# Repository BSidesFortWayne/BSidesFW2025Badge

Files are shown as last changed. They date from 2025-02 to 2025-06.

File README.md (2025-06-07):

# BSidesFW2025Badge

## How to use your badge

Here are some basic instructions to get you started using your BSides 2025 Badge!

### Navigating the Menu

When your badge initially boots it will load the default badge application and show your name.
If you would like to explore other features of the badge, you can press and hold (long press) button D.

Button D is located at the top corner of the badge and can be long pressed while using any of the
applications to return to the main menu.

### Badge Button Descriptions

RST: Pressing RST will reset the badge.

A: Function button, varies by App.

B: Function button, varies by App.

C: Function button, varies by App.

D: Long press (hold) D to return to menu screen from any App.

SEL: SEL (Select) button is used in most Apps and the Menu for making a selection.

(Left): Used in Apps and Menu to navigate Left or Down.

(Right): Used in Apps and Menu to navigate Right or Up.

### Badge App Functionality

(Left): This button will cycle through available colors for the font.

(Right): This button will cycle through available colors for the background.

A: This button will change the lower display to have the BSides Fort Wayne 2025 logo.  
++++_note: using the (Left) or (Right) buttons will switch the display back to showing company name and status_++++

D: Long press (hold) D to return to the Main Menu

Settings will save between power cycles.

## Development: Getting Started

### Tools

The python packages in this repository are managed by `uv`. The repository structure is as follows

- `.venv`: This folder will be installed when you set up the python virtual environment with uv
- `.vscode`: Vscode specific settings for this project
- `schematics`: Board schematics as PDF
- `src`: The embedded code for deployment on the target
- `STLs`: Screen bezels, supports, and PCB STLs
- `typings`: Custom typings for the VSCode Python Language Server in order to get better typehints and support for the micropython code

### Setup

Install `uv` ([getting started](https://docs.astral.sh/uv/getting-started/installation/)) based on your OS of choice. If on Windows, you may have a better development experience in `WSL` if you can provide access to the ESP32 chip to the WSL instance ([Connect USB devices](https://learn.microsoft.com/en-us/windows/wsl/connect-usb)). However, `uv` and `mpremote` both work on Windows so you can also develop natively

### Using `mpremote` for on board development

Once you have `uv` setup, you can simply run

```shell
uv sync
```

to get the virtual environment set up. Once you plug in and turn on your dev board, you need to change the device permissions (Linux only)

```shell
sudo chmod a+x /dev/ttyUSB0
```

Please see [The Programming Guide](./PROGRAMMING.md) for more details

### Hardware

Please see [The Hardware Specifications](./HARDWARE.md) for more details

### Off Board Unit Tests

`pytest` is used to run any hardware independent unit tests in the `tests/` folder with
the following command

```shell
uv run pytest tests
```

This runs the pytest command out of the `tests` folder.

TODO: Perhaps we can reference the src/ folder so that we can move the files in `src/test` to
`tests` to keep as functional tests? But they are different in that we will run the functional
onboard tests with `mpremote run src/test/<test_file.py>`

## Custom Base Image Instructions

```bash
# Move to BSFW Custom Firmware
cd BSidesFW2025Badge/firmware

# Sync uv with project
uv sync

# Erase current flash and write new flash binary
uv run esptool.py erase_flash
uv run esptool.py --baud 460800 write_flash 0x1000 BSFWCustom_firmware_SPIRAM_with_GC9A01.bin
```

Please see the [Firmware Writeup](./firmware/README.md) for more information.

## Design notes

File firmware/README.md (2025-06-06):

# Custom Badge Firmware

Our custom badge firmware binary was developed with C modules and drivers already compiled into the MicroPython source code. This firmware is required for the CTF challenges as many of the challenges rely on custom C compiled into the MicroPython image in order to operate.

**BSFWCustom_firmware_SPIRAM_with_GC9A01.bin** - This binary includes MicroPython 1.26.0, our custom Badge Challenges, and the Russ Hughes GC9A01 MicroPython C-Based Display driver.

The binary can be easily flashed to your board with the following commands:

```shell
uv run esptool.py erase_flash
uv run esptool.py --baud 460800 write_flash 0x1000 <location_of_your_downloaded_bin_file>

# e.g.
uv run esptool.py --baud 460800 write_flash 0x1000 ~/Downloads/BSFWCustom_firmware_SPIRAM_with_GC9A01.bin
```

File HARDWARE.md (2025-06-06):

## Technical Specifications V4

This section describes the technical specifications of the board to aid in development.

### Schematic Overview

Within the [schematics/Badge Schematic V4.pdf](https://github.com/commputethis/BSidesFW2025Badge/blob/68bb887bfc6d0544537c8bf179ed645db8c0f13b/schematics/BSides%20Badge%20V2%20Schematic.pdf) you will find the electrical schematic of the device including the part numbers and connections between components identified as net labels. Each section of the schematic will be described below and applicable datasheets will be linked.

### ESP32-WROVER-E-N8R8

This section contains the ESP32-WROVER-E-N8R8 itself, the decoupling capacitors, the pullup resistors required for operation of the I2C Bus, and the net labels associated with the GPIO pins of the ESP32. The ESP32-WROVER-E-N8R8 has a 240Mhz Dual Core processor with 8Mb of Flash and 8Mb of RAM available on the SPI bus.

Datasheets:
[ESP32 Wrover E/IE](https://www.espressif.com.cn/sites/default/files/documentation/esp32-wrover-e_esp32-wrover-ie_datasheet_en.pdf)

### USB-Serial

This board uses a CH340C USB to Serial chip to allow for programming via USB-C connector. When connected to USB-C your computer should detect a USB to Serial interface resulting in the creation of a COM port much like any ESP32 or Arduino style device.

### USB-C

This section contains the USB-C shell connector and associated netlabels. CC1 and CC2 are connected to 5.1k resistors to request basic 5V low power from the USB-C device connected. DP and DN data connectors are connected to the CH340C to facilitate communication with the ESP32 via the UART.

### WS2812B

This section contains the seven WS2812 RGB LEDs connected to IO26. There is not much more to say about this. Treat it like a small LED strip.

[Worldsemi WS2812B-B/T](https://www.lcsc.com/product-detail/RGB-LEDs-Built-in-IC_Worldsemi-WS2812B-B-T_C2761795.html)

### RTS/DTR Circuit

This section contains a dual transistor package that is used to place the ESP32 into programming mode and reset mode based on the RTS/DTR output of the CH340C driven by the attached programming software application.

### Boot/Function Buttons

These are the four buttons across the top of the device, to the right of the ESP32, and three gaming buttons. SW1 is dual-purpose. During normal operation, it serves as a simple button attached to IO0. However, IO0 is a strapping pin dedicated to placing the ESP32 into the boot (programming) mode. If SW1 is held during startup, the device will be manually placed into boot mode. This should not be required during normal programming sessions, as the RTS/DTR circuit should handle this function, but it is available if needed in special circumstances. SW2, SW3, SW4, SW7, SW8, and SW9 are basic buttons connected to a PCA9535 IO expander at address 0x20 on the I2C bus. All lines are pulled high and are active low.

SW1 > IO0

SW2 > IO1_2

SW3 > IO1_1

SW4 > IO1_0

SW7 > IO0_2

SW8 > IO0_1

SW9 > IO0_0

### Reset Button

Connected to the EN pin of the ESP32. Pressing this will reset the device.

### LIS3DHTR Accelerometer I2C Address 0x18

This section contains the accelerometer (LIS3DHTR) and the associated connections. The datasheet is linked for reference. The I2C data lines are connected to IO22 (SCL) and IO21 (SDA) on the ESP32, and the accelerometer can be accessed at I2C address 0x18. IO34 is also dedicated to a programmable interrupt pin on the accelerometer for possible use. An example of this device would be for power saving. If no motion is detected for an interval, the device could be put into a reduced power state and then later woken up using the interrupt pin. Of course, there are plenty of other fun things that can be accomplished using the three-axis output of the accelerometer. The unused interrupts and ADC inputs are wired to the expansion headers for future use.

Datasheet: [LIS3DH](https://www.st.com/resource/en/datasheet/lis3dh.pdf)

### Battery Monitor

This is a straightforward voltage divider that represents the current voltage of the LIPO 3.7V nominal battery. It is read via ADC1 on the Accelerometer on the I2C bus. The divider ratio is 0.2985, resulting in a fully charged battery at 4.2V sending 1253 mV to ADC1, and a fully discharged battery at 3.0V will result in 895 mV at ADC1. Admittedly, this is not the best method of determining battery charge status, but it's better than nothing, and with some simple code to average the readings and correct the non-linearity of LIPO discharge rates, it can be effective at gauging basic SOC levels.

### DW01A Battery Protection

This is a safety feature to prevent damage to the battery due to overcharging or over-discharging. It will disable the battery in the event of any anomaly. It's a very commonly used circuit to manage single-cell lithium battery safety.

### Battery Charger TP4056

This is a single-cell lithium battery charger circuit. It will charge at up to ~900ma using the power delivered from the USB-C VBUS and will manage the charging of the lithium cell. Two LEDs indicate charge status. Red = Charging, Green = Fully Charged.

### Boost Buck 3V3

This is the primary switching power converter and takes its input from the VCC network (Post power switch, battery protection, and fuse) and converts that into a stable 3.3V for the board Components. This power module (TPS63060DSCR) is a boost buck module and can accept input voltages in a wide range to deliver a consistent 3.3V output. This module is running anytime the power switch is in the on position and a battery is connected.

Note: This device is not designed to operate without a battery. The battery provides voltage stability that the boost buck converter requires for reliable operation. Operating the device from USB power with no battery is not recommended and will result in undesirable power fluctuations.

### Power Switch

Simple... It's a switch. Turn it on to use it.

### Display Headers

These are the 7-pin female headers that the screens plug into and the transistors that control the display's power. The DISP_EN network is connected to IO32, which controls the power status of the displays. Bringing IO32 high will enable the displays, and bringing it low will disable them. IO32 can be used to save power when not in use. By default, IO32 is pulled low, and the displays will be off normally.

The Screens are connected to the SPI data bus and can operate independently via software using the Data Control, Reset, and Chip Select Pins. The pinouts are below.

Common Pins for SPI Bus:

MOSI > IO23

CLK > IO18

Screen 1 Pins:

DC1 > IO19

RST1 > IO14

CS1 > IO33

Screen 2 Pins:

DC2 > IO25

RST2 > IO27

CS2 > IO13

### Speaker

There is a "speaker" (really a variable frequency buzzer). You can send tones by adjusting the PWM frequency and varying the volume by changing the PWM duty cycle, although this method may yield mixed results at different frequencies. This is connected to IO15 of the ESP32. Datasheet below:

[HYDZ HYG-7525A-5027](https://www.lcsc.com/product-detail/Buzzers_HYDZ-HYG-7525A-5027_C18623827.html)

### Expansion Headers

V2 contains two expansion headers. In V4 these will not be populated with headers and will be available to anyone who wants to hack these devices and use IO that is not used by anything else on the board. The Pinouts are referenced on the Schematic as well as the silkscreen on the back of the board. (H3 and H4). H4 is closest to the top of the board.

### Input/Output Expander 0x20

This is a PCA9535 IO expander at address 0x20 on the I2C bus IO22 (SCL) and IO21 (SDA). The PCA9535 provides an additional 16 GPIO lines via the I2C bus and in this application is used to read the status of buttons. For details about the buttons refer to the Boot/Function Buttons section. The unused IO lines are wired to the expansion headers for future use.

### ESP32 GPIO Pin Assignments

IO0    Boot/Button 1 (Strapping)

IO2    (Strapping) Not Connected

IO4    (Strapping) Not Connected

IO5    (Strapping) Not Connected

IO12   (Strapping) Not Connected

IO13   CS2

IO14   RST1

IO15   (Strapping) Speaker

IO18   CLK

IO19   DC1

IO21   I2C SDA

IO22   I2C SCL

IO23   MOSI

IO25   DC2

IO26   WS2812B

IO27   RST2

IO32   DISP_EN

IO33   CS1

IO34   Accelerometer Interrupt

IO35   Not Connected

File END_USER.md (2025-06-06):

# End User Usage

## Types of Users

- [ ] Badge Barry
  - Programs badge at registration, never touches
  - Cares about a badge that runs all day/low power detection mode
- [ ] Tinkerer Tina
  - Wants to play around with their badge to try apps or change settings
  - Might connect their badge to WiFi
  - Need better on-board configuration and app selections
- [x] Script Kiddie Sam
  - Wants to modify existing apps and write basic code
  - May be overwhelemed by project setup but can use WiFi landing page to modify or upload new single-file apps
- [x] Hacker Hanna
  - Wants to set up the dev environment on their computer to play with the badge, largely by playing with the exiting micropython code base, but wants to do it in their editor for full deployment control
  - Need access to the GitHub repo for the source code (to be released post conference because of CTF things on the badge)
- [x] Embedded Eddie
  - Will set up the `esp-idf` himself and load his own custom images
  - Would benefit most from schematics

## Adding custom apps

- Start up badge
- Put into AP mode
- Open page to add app /apps
  - Text editor to paste code
  - Download examples

## Modify app configurations

- Start up badge
- Put into AP mode
- Open page to change config (/config.html)
- Edit configs in recursive menu
  - Make HTML tables based on
  - `bool`, `str`, `int`, and `float` properties can be editable fields in table
  - `dict` objects in config can be sub-tables (should be avoided)

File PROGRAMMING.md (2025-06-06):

You can erase the flash and then flash the board with the above image with the following commands

```shell
uv run esptool.py erase_flash
uv run esptool.py --baud 460800 write_flash 0x1000 <location_of_your_downloaded_bin_file>

# e.g.
uv run esptool.py --baud 460800 write_flash 0x1000 ~/Downloads/firmware_SPIRAM_8MiB.bin
```

And then you can either mount the `src` directory for the board and start in a REPL

```shell
uv run mpremote mount src
```

Or deploy the source to the board directly

```shell
# This will deploy all src, but mpremote will check the hash of the files to determine 
uv run mpremote cp -r src/* :
```

Here are some other useful patterns with `mpremote`

```shell
# when developing and iterating quickly, we can use this to deploy the file you are working on and then running `main` from local
# in one command
uv run mpremote cp -r src/apps/analog_clock.py + run main.py
```

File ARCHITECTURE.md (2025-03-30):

# Architecture Diagrams

## Module/App Design Constructors

- Files (also called modules) in the `apps/` folder will be auto-ingested for potential apps to run
- A module can have multiple apps
- Apps MUST inherit from the base class
- App minimum requirements are very light
- Base App class will provide
  - Automatic app registration (thanks to app directory)
  - Automatic serialization/deserialization of configs
    - Not required to use, but helps group configs for UI and web based config edits
    - (Not Done) Support for displaying in apps menu with custom icons and names
    - (Not Done) Abstracted registraiton functions for button handling and other hardware based callbacks that can be automatically de-registered as well

## Button Constructs

- Long presses are good for "exiting" context
- Should be used minimally
- Should come up with unified button handling that is mostly outside of app control for existing an app/going back to the menu

## Main Startup Sequence

```mermaid
flowchart TD
    badgeApp["Badge App"]
    loadAppCache["Load App Cache"]
    modulesChanged{"Files Changed?"}
    showLoadingScreen["Show Loading Screen"]
    errorParsing{"Error <br> Loading New <br> Modules?"}
    reparseChangedModules["Parse Modules"]
    storeNewConfiguration["Store New <br> Configuration"]
    revertToOldConfig["Disable Module, <br> Write to error.txt"]

    loadAppCache-->
    modulesChanged--"Yes"-->
    
    showLoadingScreen-->
    reparseChangedModules-->
    errorParsing--"No"-->storeNewConfiguration-->badgeApp
    errorParsing--"Yes"-->revertToOldConfig-->badgeApp

    badgeApp

    modulesChanged--"No"-->badgeApp

```

## Config

- The base app provides a `Config` object that can allow the apps to be dynamically configured via the `/config` 
endpoint. When an app is open, the endpoint can be visited and any app settings that were registered can be adjusted. 
The `analog_clock.py` shows an example of this. Currently basic types like `str` and `int` are supported, as well as 
various smart config objects. Check out `lib/smart_config.py` for more information. The base `SmartConfig` class is
itself a dictionary for easy serialization and deserialization to a JSON config file
- Smart Config Types
  - `EnumConfig`: Allows you to specify a config object form a list of options. Renders as an HTML dropdown
  - `BoolDropdownConfig`: Inherits from enum config for boolean selection. Unfortunately HTML checkboxes don't act in 
  normal ways in HTML forms so to avoid a larger payload to patch that behavior, we just use this instead for bools
  - `RangeConfig`: Allows you to specify a number value with a range that is then rendered as an HTML slider
  - `ColorConfig`: Inherits from `RangeConfig` and specifics the normal 565 color limits for the gc9a01 display

- (Not Done) The Smart Config class will also be renderable as UI elements on the screens themeselves. The inputs
should generally match what is available on the HTML config page (sliders, dropdowns, numeric entries, etc)

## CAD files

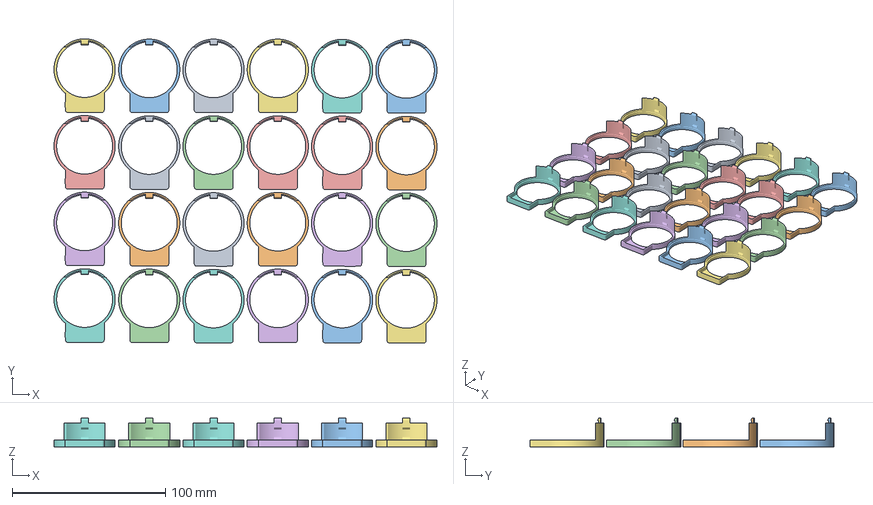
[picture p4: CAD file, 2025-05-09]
STLs/BSides2025-ScreenBezelV4_Full_Plate.3mf
250.2 x 198.8 x 18.8 mm
1.28_TFT_screen_cover_V4.stl x 2
1.28_TFT_screen_cover_V4.stl 11
1.28_TFT_screen_cover_V4.stl 2
1.28_TFT_screen_cover_V4.stl 3
1.28_TFT_screen_cover_V4.stl 4
1.28_TFT_screen_cover_V4.stl 5
1.28_TFT_screen_cover_V4.stl 6
1.28_TFT_screen_cover_V4.stl 7
1.28_TFT_screen_cover_V4.stl 8
1.28_TFT_screen_cover_V4.stl 9
1.28_TFT_screen_cover_V4.stl 10
1.28_TFT_screen_cover_V4.stl 1
1.28_TFT_screen_cover_V4.stl 12
1.28_TFT_screen_cover_V4.stl 13
1.28_TFT_screen_cover_V4.stl 14
1.28_TFT_screen_cover_V4.stl 15 x 2
1.28_TFT_screen_cover_V4.stl 16 x 2
1.28_TFT_screen_cover_V4.stl 17 x 2
1.28_TFT_screen_cover_V4.stl 18 x 2

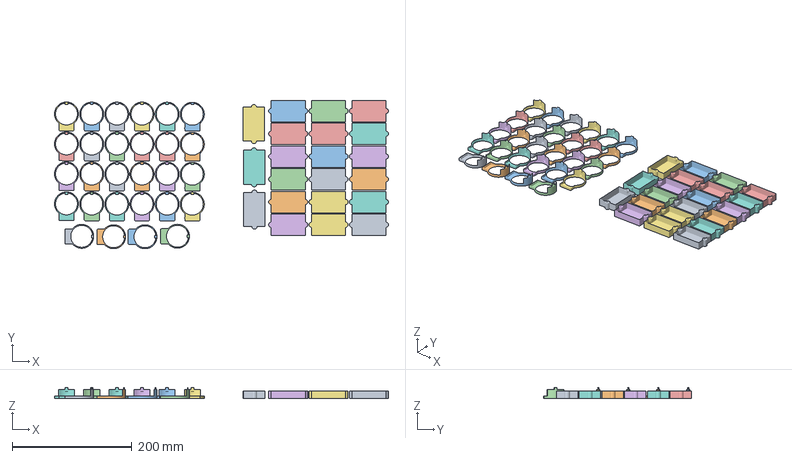
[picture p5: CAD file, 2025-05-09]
STLs/BSides2025-badge-final-print.3mf
557.9 x 248.0 x 18.8 mm
1.28_TFT_screen_cover_V4.stl x 2
1.28_TFT_screen_cover_V4.stl 11
1.28_TFT_screen_cover_V4.stl 2
1.28_TFT_screen_cover_V4.stl 3
1.28_TFT_screen_cover_V4.stl 4
1.28_TFT_screen_cover_V4.stl 5
1.28_TFT_screen_cover_V4.stl 6
1.28_TFT_screen_cover_V4.stl 7
1.28_TFT_screen_cover_V4.stl 8
1.28_TFT_screen_cover_V4.stl 9
1.28_TFT_screen_cover_V4.stl 10
1.28_TFT_screen_cover_V4.stl 1
1.28_TFT_screen_cover_V4.stl 12
1.28_TFT_screen_cover_V4.stl 13
1.28_TFT_screen_cover_V4.stl 14
1.28_TFT_screen_cover_V4.stl 15 x 2
1.28_TFT_screen_cover_V4.stl 16 x 2
1.28_TFT_screen_cover_V4.stl 17 x 2
1.28_TFT_screen_cover_V4.stl 18 x 6
BSides2025_Battery_Cover_V4.stl
BSides2025_Battery_Cover_V4.stl 17 x 4
BSides2025_Battery_Cover_V4.stl 16
BSides2025_Battery_Cover_V4.stl 1
BSides2025_Battery_Cover_V4.stl 15
BSides2025_Battery_Cover_V4.stl 14
BSides2025_Battery_Cover_V4.stl 13
BSides2025_Battery_Cover_V4.stl 12
BSides2025_Battery_Cover_V4.stl 11
BSides2025_Battery_Cover_V4.stl 10
BSides2025_Battery_Cover_V4.stl 9
BSides2025_Battery_Cover_V4.stl 8
BSides2025_Battery_Cover_V4.stl 7
BSides2025_Battery_Cover_V4.stl 6
BSides2025_Battery_Cover_V4.stl 5
BSides2025_Battery_Cover_V4.stl 4
BSides2025_Battery_Cover_V4.stl 3
BSides2025_Battery_Cover_V4.stl 2

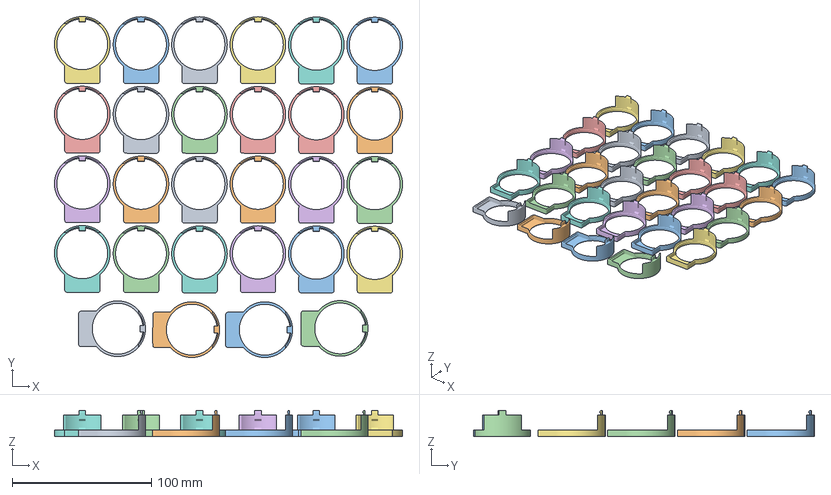
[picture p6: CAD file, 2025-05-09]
STLs/BSides2025-ScreenBezelV4.3mf
250.2 x 245.1 x 18.8 mm
1.28_TFT_screen_cover_V4.stl x 2
1.28_TFT_screen_cover_V4.stl 11
1.28_TFT_screen_cover_V4.stl 2
1.28_TFT_screen_cover_V4.stl 3
1.28_TFT_screen_cover_V4.stl 4
1.28_TFT_screen_cover_V4.stl 5
1.28_TFT_screen_cover_V4.stl 6
1.28_TFT_screen_cover_V4.stl 7
1.28_TFT_screen_cover_V4.stl 8
1.28_TFT_screen_cover_V4.stl 9
1.28_TFT_screen_cover_V4.stl 10
1.28_TFT_screen_cover_V4.stl 1
1.28_TFT_screen_cover_V4.stl 12
1.28_TFT_screen_cover_V4.stl 13
1.28_TFT_screen_cover_V4.stl 14
1.28_TFT_screen_cover_V4.stl 15 x 2
1.28_TFT_screen_cover_V4.stl 16 x 2
1.28_TFT_screen_cover_V4.stl 17 x 2
1.28_TFT_screen_cover_V4.stl 18 x 6

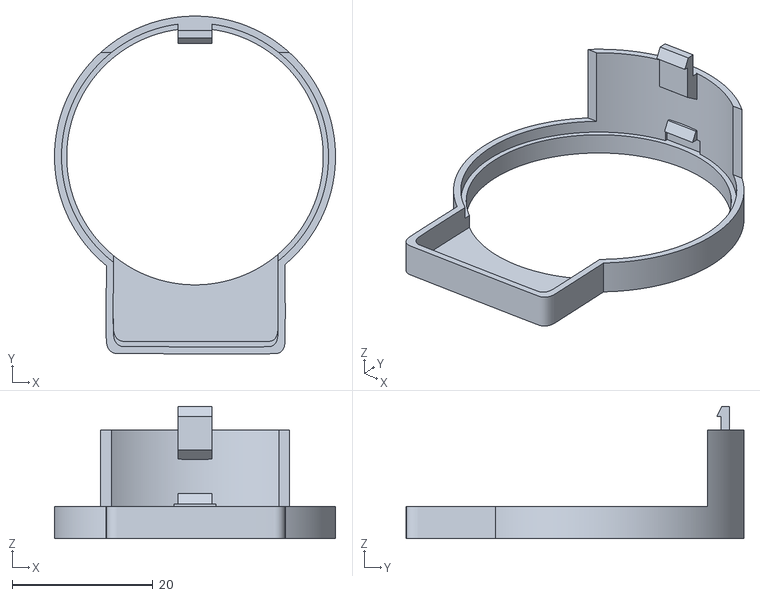
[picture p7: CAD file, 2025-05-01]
STLs/BSides2025-ScreenCoverV4.stl
40.0 x 48.1 x 18.8

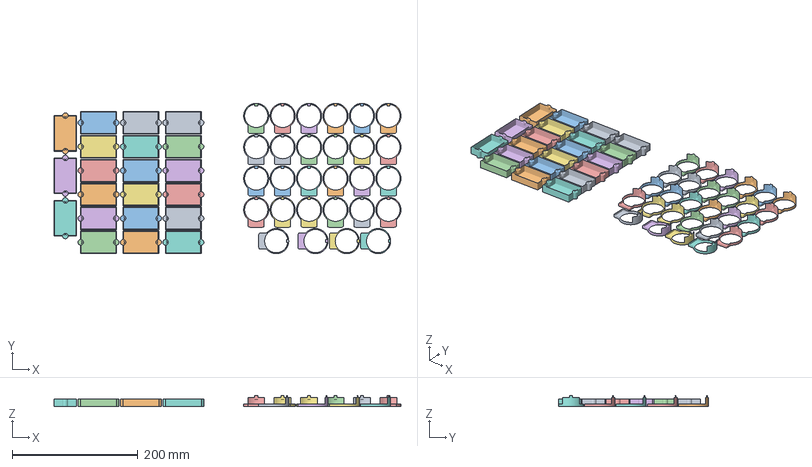
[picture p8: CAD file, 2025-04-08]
STLs/BSides2025-Badge_Covers.3mf
551.3 x 238.9 x 18.1 mm
Badge_Battery_Cover.stl 17
BSides2025-ScreenCoverV3.stl 21
BSides2025-ScreenCoverV3.stl
Badge_Battery_Cover.stl 2
BSides2025-ScreenCoverV3.stl 22
Badge_Battery_Cover.stl 3
BSides2025-ScreenCoverV3.stl 11
Badge_Battery_Cover.stl 4
Badge_Battery_Cover.stl 5
BSides2025-ScreenCoverV3.stl 2
Badge_Battery_Cover.stl 6
BSides2025-ScreenCoverV3.stl 3
Badge_Battery_Cover.stl 7
BSides2025-ScreenCoverV3.stl 4
Badge_Battery_Cover.stl 8
BSides2025-ScreenCoverV3.stl 5
Badge_Battery_Cover.stl 9
BSides2025-ScreenCoverV3.stl 6
Badge_Battery_Cover.stl 10
BSides2025-ScreenCoverV3.stl 7
Badge_Battery_Cover.stl 11
BSides2025-ScreenCoverV3.stl 8
Badge_Battery_Cover.stl 12
BSides2025-ScreenCoverV3.stl 9
BSides2025-ScreenCoverV3.stl 10
Badge_Battery_Cover.stl 13
Badge_Battery_Cover.stl 14 x 4
BSides2025-ScreenCoverV3.stl 1
BSides2025-ScreenCoverV3.stl 12
Badge_Battery_Cover.stl 15
BSides2025-ScreenCoverV3.stl 13
Badge_Battery_Cover.stl 1
BSides2025-ScreenCoverV3.stl 14
Badge_Battery_Cover.stl 16
BSides2025-ScreenCoverV3.stl 15
Badge_Battery_Cover.stl
BSides2025-ScreenCoverV3.stl 16
BSides2025-ScreenCoverV3.stl 17
BSides2025-ScreenCoverV3.stl 18
BSides2025-ScreenCoverV3.stl 19
BSides2025-ScreenCoverV3.stl 20
BSides2025-ScreenCoverV3.stl 23 x 5

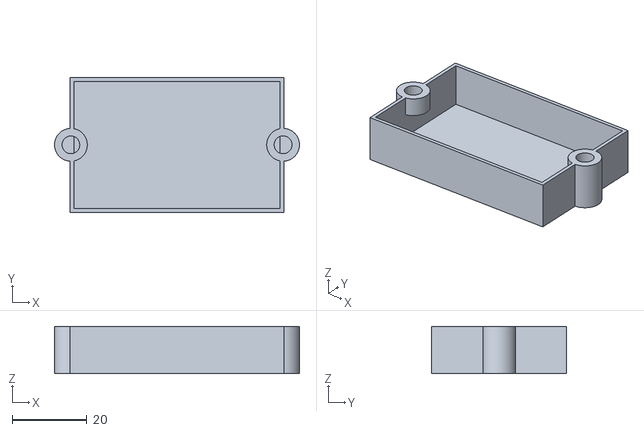
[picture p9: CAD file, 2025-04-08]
STLs/BSides2025_Battery_Cover_V5.stl
65.4 x 36.0 x 12.6

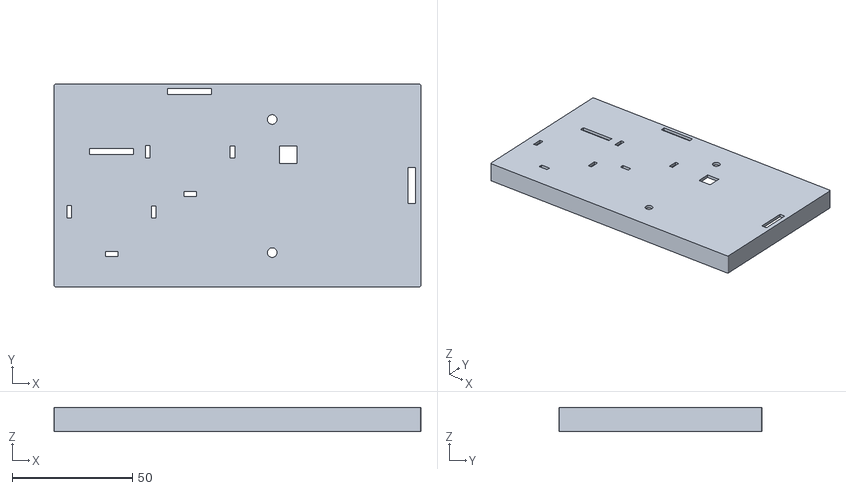
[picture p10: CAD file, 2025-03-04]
STLs/BSidesV2-Badge-Slot-Layout.stl
152.7 x 84.5 x 10.0

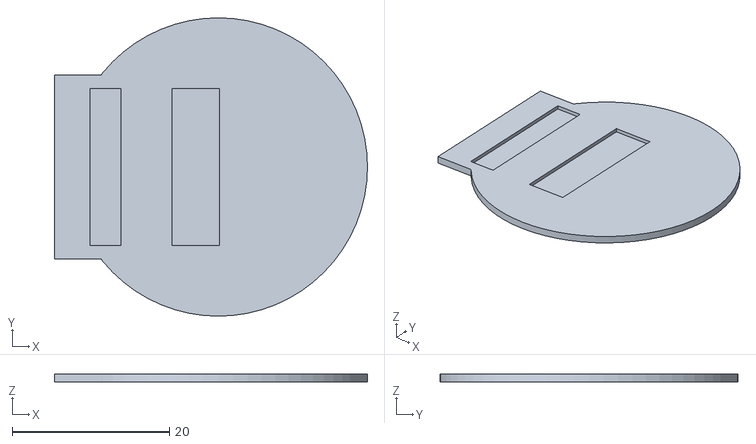
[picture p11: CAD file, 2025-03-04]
STLs/BSides2025-ScreenSupport.stl
39.9 x 38.0 x 1.05

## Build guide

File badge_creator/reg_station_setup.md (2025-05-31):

# Steps to setup registrations stations

This assumes this is a dedicated machine installed for this purpose.  This guide does not go over how to create a bootable Ubuntu usb drive.  A couple things to keep in mind:

- Keep the passwords consistent for ease of those managing the registration area
- Keep machine names consistent, but different (i.e. reg1, reg2, etc.)

## Ubuntu OS Install

1. Place the Ubuntu bootable USB drive into the powered off computer.
2. Power On the machine and boot to the USB Drive.
3. Select Install Ubuntu
4. Follow the prompts keeping the following in mind:
   1. Use Minimal install.
   2. Use "registration" as the username and login name.
   3. The password can be what ever you want, just follow the tip from above.
   4. Select the option to login automatically
   5. The rest of the options are up to you based on your preference.
5. Once the install is completed, select reboot.
6. You will then be asked to remove the USB drive and then press Enter.
7. Skip connecting online accounts.
8. Skip enabling ubuntu pro.
9. Answer how you wish on sending info to improve ubuntu
10. Location services are not needed.
11. No extra apps needed.
12. It will likely ask if you want to install updates. Proceed with doing so and restart when finished.

## Configure OS

1. Open Settings and set preferences as needed.  I do the following:
    1. Appearance - Dark theme
    2. Privacy > Screen
        1. Blank Screen Delay - Never
        2. Automatic Screen lock - off
        3. Lock Screen on Suspend - off
2. Install required components and copy scripts to the machine. This can be done by copying the badge_creator directory to the Documents directory on the registration machine and running the reg_station_setup.sh script from the machine.  So, put that on a usb drive and get it copied onto the machine.
   1. Sometimes, the run_badger_creator.sh file on the Desktop will show a lock on it in File Explorer and be owned by the root user. This will cause it not to work.  To fix that, just create a copy of the file, delete the old one, and rename the copy to the original name.
   2. The same thing happens with the /Documents/Badger_2040_Badge_Creator folder also.  Do the same thing to fix it.  However, after copying it, you can't just move it to trash, you must go to the terminal and run ```sudo rm /home/registration/Documents/Badger_2040_Badge_Creator -r```
3. Need to make the run_badger_creator.sh file be able to run as an application.
   1. Right Click on the file and select Properties.
   2. On the Permissions tab, check the Execute box
   3. Close the Properties box
4. Add Run Badger Creator to Startup Applications
   1. Open Dash (the first icon in the side bar)
   2. Click on Startup Applications
   3. Click the Add button
   4. Type in "Run Badge Creator" in Name
   5. Click the Browse button
   6. Double-click Desktop
   7. Click run_badger_creator.sh
   8. Click the Open button
   9. Click the Add button
   10. Click the Close button
5. Reboot the machine

All the remains now is to test a badge.  If for some reason the badger_gui script didn't run on startup, run it manually from terminal to see if there are errors.

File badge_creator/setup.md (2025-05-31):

# Setup Linux to be able to run these scripts

This assumes Linux (either Ubuntu or Raspberry Pi OS) is already installed.

- [Setup Linux to be able to run these scripts](#setup-linux-to-be-able-to-run-these-scripts)
  - [Install Python3](#install-python3)
  - [Install pip3](#install-pip3)
  - [Install pil](#install-pil)
  - [Install pipx](#install-pipx)
  - [Install rshell](#install-rshell)
  - [Install Tkinter](#install-tkinter)
  - [Install uv](#install-uv)
  - [Install mpremote](#install-mpremote)
  - [Add user to the dialout group](#add-user-to-the-dialout-group)

## Install Python3

Check to see if Python3 is installed by running the following from terminal:  

- `python3 -V`

If the version isn't returned, then run the following:

- `sudo apt install python3`

## Install pip3

Check to see if pip3 is installed by running the following from terminal:

- `pip3 -V`

If the version isn't returned, then run the following:

- `sudo apt install python3-pip`

## Install pil

Install pil and pil.imagetk using the following from terminal:

- `sudo apt install python3-pil pythong3-pil.imagetk`

## Install pipx

`sudo apt install pipx`

## Install rshell

- `sudo apt install pyboard-rshell`

## Install Tkinter

Install Tkinter using the following from terminal:

- `sudo apt install python3-tk`

## Install uv

- `wget -qO- https://astral.sh/uv/install.sh | sh`

## Install mpremote

- `pipx install mpremote`

## Add user to the dialout group

Add user to the dialout group so it can communicate with the Badges through the serial port (USB). Use the following from terminal (replace username with the user the script will be run by):

- `sudo usermod -a -G dialout username`

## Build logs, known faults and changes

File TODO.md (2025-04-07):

# To Do List

- Hardware
  - Drivers
    - [x] Audio
    - [x] Buttons
    - [x] Displays
    - [x] LEDs
    - [x] LIS3DH
    - [x] PCA9535
- UI
  - [ ] Base display tools to abstract framebuf usage
  - 
- 

- Design artifacts
  - [x] User flows/User types
  - [ ] Initial programming flowchart
  - [ ] Software startup routines
  - [ ] Smart Config Architecture
- Software
  - [x] App Directory
    - [x] Clean up app directory
  - [ ] Base App
  - [ ] Controller
    - [ ] Add error screen/error logging to app loading
  - [ ] UI
    - [ ] Make loading/pop up screen design for any views to use
    - [ ] Normalize rendering around async?
      - [ ] Have options for popups, confirmation dialogs, multi choice selections, etc
      - [ ] "Modal" contexts
    - [ ] Network
      - [ ] Add option to connect to local network
      - [ ] Add option to set up in station mode and display QR code
      - [ ] Make simple HTTP server construct (for a module to listen for a specific URL/port?)
- Hardware improvements
  - [x] Add button listeners for press, release, and click
  - [x] Add high level config for hardware version (no point to waste v1 hardware, and then we can share code more easily)
  - [x] Implement IO expander support in `buttons` module (not sure if it needs to just be polled or if we want to make it interrupt driven...)
  - [x] Implement standalone `led` module and add some convenience function
  - [x] Battery meter hardware support?
    - [ ] Battery monitor screen/utility
  - [x] Add accelerometer hardware module
  - [ ] System monitor utility (RAM, storage, etc)
  - [x] Add speaker module
    - [ ] MIDI transforms?
  - [ ] Better display functions
  - [ ] Frame buffer based driver module
  - [ ] LED bug
  - [ ] Test Suite
    - [ ] Speaker driver test (async background?)
  - [ ] MicroPython RTC support?
  - [ ] Low power mode for all day badge usage
- Refactors
  - [x] Make a base `hardware` class that gets called back regularly on the main thread for polling reasons
  - [x] Redesign base `view` concept into `apps` and make `views` class into `controller` for better variable naming/lack of confusion
  - [x] Migrate some hardware setup to `boot.py` for better REPL usage (Dependent on v1/v2 hardware switching)
  - [x] Figure out how to add stubs for better type hint support (I added more `#type: ignore` where appropriate to get better static checking help in VSCode)
- Display
  - [x] QR code generator/displayer
    - [x] [https://github.com/JASchilz/uQR](https://github.com/JASchilz/uQR)
  - [ ] Better abstraction functions/color functions
  - [ ] Make frame buffer based display class for driver abstraction
  - [ ] Dissolve/transitions between images?
    - [ ] General animation function between frame buffers
  - [ ] Ingest / transform image from user?
    - [ ] Zoom/rotate (for final image tweaks?)
    - [ ] Part of badge config
- Performance
  - [ ] Investigate increasing performance in underlying gc9a01 driver in base image/coming up with custom BSides base image
  - [ ] Initial programming could then happen via image load + config file
- Bluetooth
  - Detect BLE beacons?
    - CTF/special prize?
- User configurability
  - Add default `config` options object that can be serialized by app name and then edited via web GUI
  - Add base functionality to `App` base class which handles serialization/deserialization
  - Stored in `config/{module_name}/{app_name}/config.json`
- App Ideas
  - [ ] Badge Modes
    - [ ] Large First + Last Name
    - [ ] Images on both screen
    - [ ] QR mode for contact info
  - [ ] Clock
    - [ ] Analog Clock
    - [ ] Digital Clock
    - [ ] Clock Learning program for kids?
  - [ ] Etch a Sketch
  - [ ] 2048 (hard to implement?...)
  - [ ] Surface level based on x/y position
  - [ ] Voltage Meter
    - [ ] Battery level: Low/Medium/High
  - [ ] Reaction timer game
    - [ ] Multi-player network reaction game
  - [ ] On board image manipulation
    - [ ] Rotate
    - [ ] Zoom
    - [ ] Skew?
    - [ ] Grayscale/B&W
    - [ ] Color invert
  - [ ] Image Slideshow
    - [ ] Scroll through selected images
  - [ ] Vendor sign off app
    - [ ] Crypto key

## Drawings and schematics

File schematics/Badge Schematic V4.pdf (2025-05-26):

# Boot/Function Buttons

# Reset Button

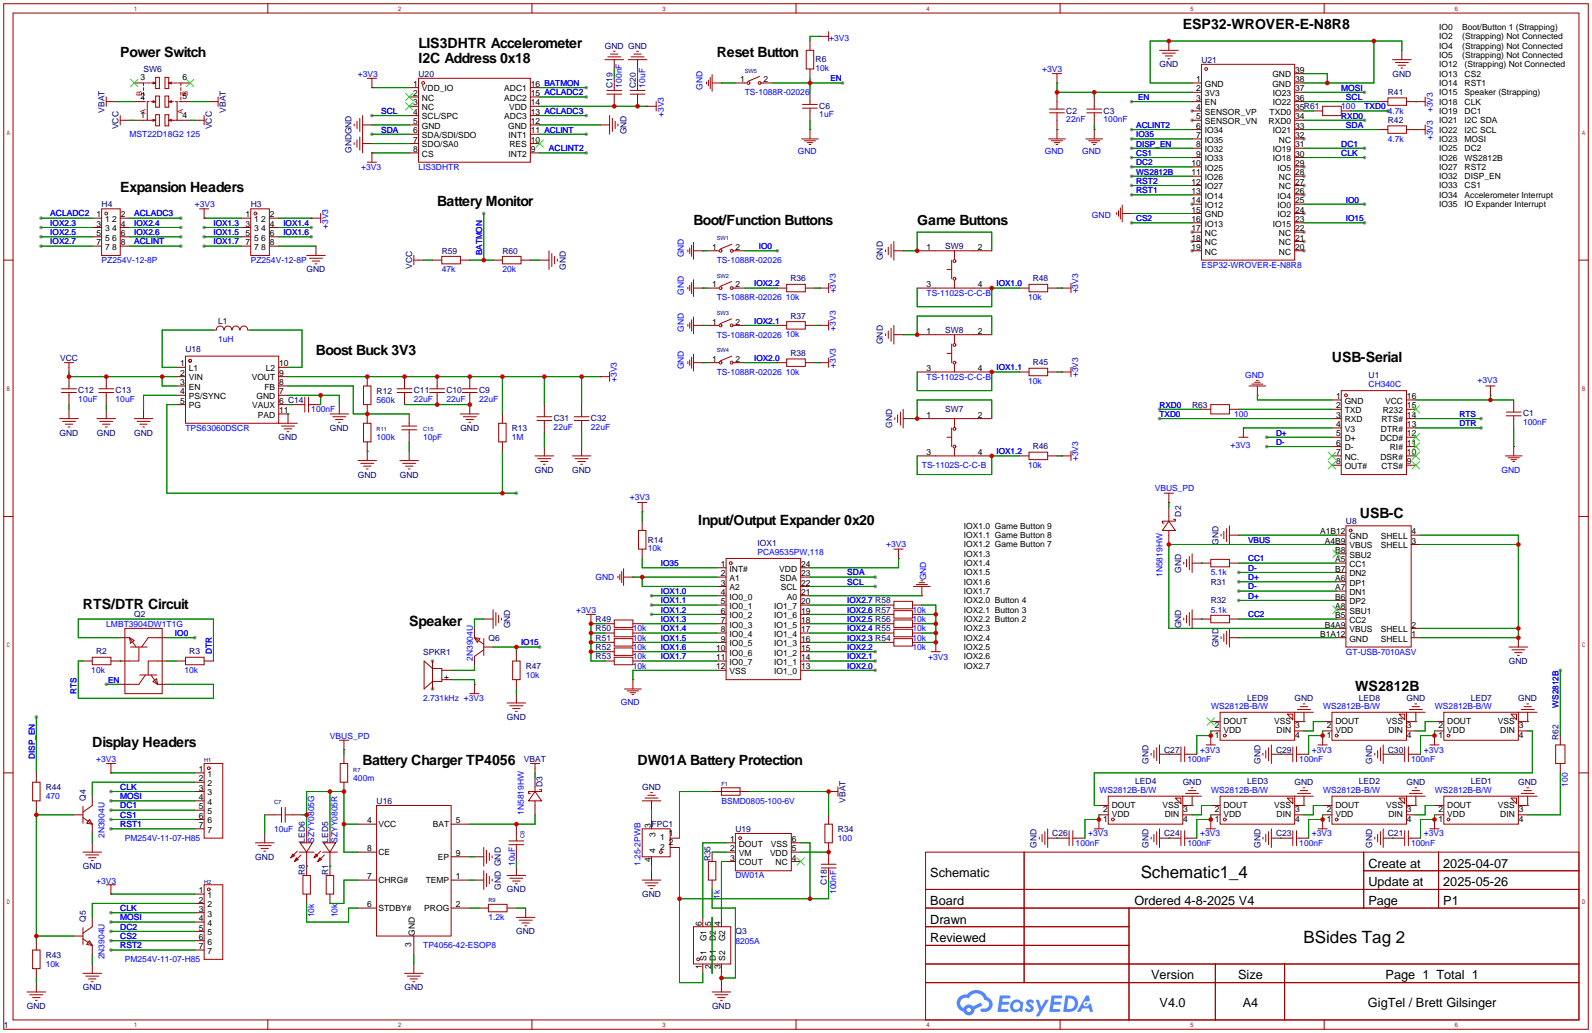
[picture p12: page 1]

NC 19 NC 18 NC 17 IO13 16 GND 15 IO12 14 IO14 13 IO27 12 IO26 11 IO25 10 IO33 9

Schematic | Schematic1_4 | Create at | 2025-04-07

Update at | 2025-05-26

Board | Ordered 4-8-2025 V4 | Page | P1
Drawn | | BSides Tag 2
Reviewed

Version | Size | Page 1 Total 1
V4.0 | A4 | GigTel / Brett Gilsinger

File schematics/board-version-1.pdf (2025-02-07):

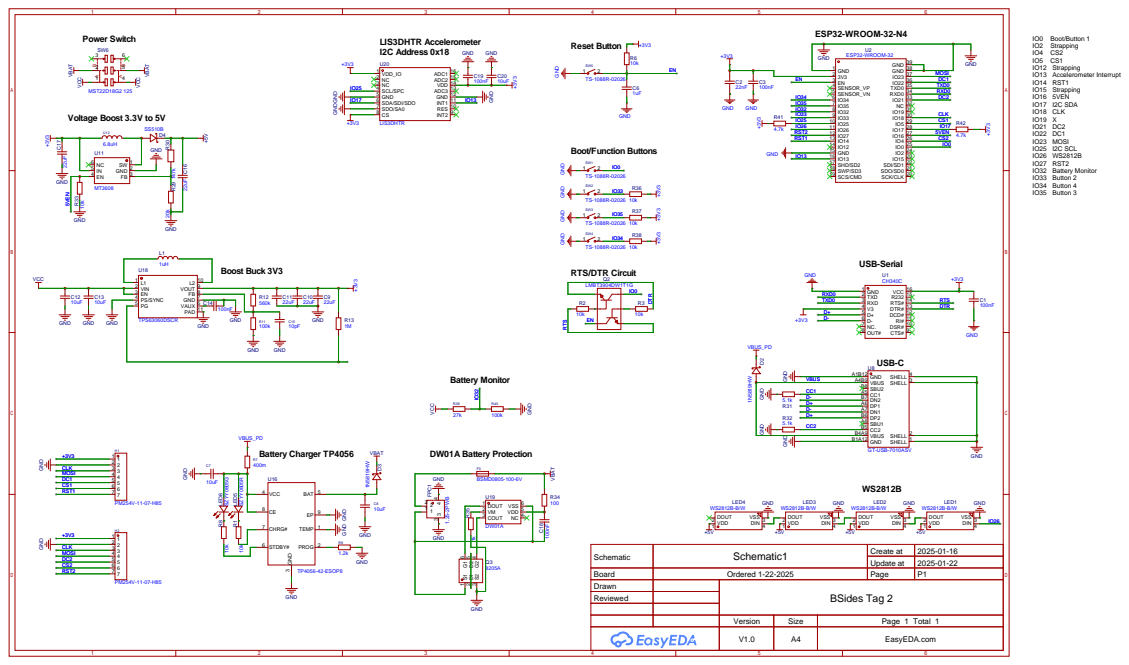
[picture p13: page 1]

Schematic | Schematic1 | Create at | 2025-01-16

Update at | 2025-01-22

Board | Ordered 1-22-2025 | Page | P1
Drawn | | BSides Tag 2
Reviewed

Version | Size | Page 1 Total 1
V1.0 | A4 | EasyEDA.com

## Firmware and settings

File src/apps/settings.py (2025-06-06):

from apps.app import BaseApp
import gc9a01 
from time import sleep_ms

import fonts.arial32px as arial32px
from lib.random_password import generate_random_password
from lib.uQR import QRCode, QRData, MODE_8BIT_BYTE
from lib.dns import MicroDNSSrv
from lib.microdot import Microdot, Response, send_file, with_form_data
from lib.microdot.utemplate import Template
import asyncio
import os
import json

from lib.smart_config import BoolDropdownConfig, ColorConfig, EnumConfig

def hex_to_rgb565(hex_color: str) -> int:
    hex_color = hex_color.lower().lstrip('#')
    if len(hex_color) != 6:
        raise ValueError("Input must be a 6-digit hex colour in RRGGBB format")

    # Split into 8-bit RGB components
    r = int(hex_color[0:2], 16)
    g = int(hex_color[2:4], 16)
    b = int(hex_color[4:6], 16)

    # Pack into 5-6-5 bits: RRRR R GGGGGG BBBB B
    rgb565 = ((r & 0xF8) << 8) | ((g & 0xFC) << 3) | (b >> 3)
    return rgb565

def rgb565_to_hex(rgb565: int) -> str:
    if not (0 <= rgb565 <= 0xFFFF):
        raise ValueError("Value must be in the range 0x0000–0xFFFF")

    # Extract 5-6-5 bit fields
    r5 = (rgb565 >> 11) & 0x1F       # 5 bits for red
    g6 = (rgb565 >> 5)  & 0x3F       # 6 bits for green
    b5 =  rgb565        & 0x1F       # 5 bits for blue

    # Expand to 8-bit channels:
    # 5-bit -> 8-bit: replicate the high 5 bits (<<3) and copy top 3 again (>>2)
    # 6-bit -> 8-bit: replicate the high 6 bits (<<2) and copy top 2 again (>>4)
    r8 = (r5 << 3) | (r5 >> 2)
    g8 = (g6 << 2) | (g6 >> 4)
    b8 = (b5 << 3) | (b5 >> 2)

    return f'#{r8:02X}{g8:02X}{b8:02X}'

class App(BaseApp):
    name = "Settings"
    def __init__(self, controller):
        super().__init__(controller)
        self.display1 = self.controller.bsp.displays.display1
        self.display2 = self.controller.bsp.displays.display2

        self.bg_color = gc9a01.WHITE
        self.fg_color = gc9a01.BLACK
        
        self.font = arial32px

        self.center = self.display1.width() // 2

        self.display1.fill(gc9a01.WHITE)
        self.display2.fill(gc9a01.WHITE)
        self.badge_id = generate_random_password()

        self.config['test_config_var'] = 'test'
        self.config.add('test_bool_config', BoolDropdownConfig('Test Bool Config', True))
        self.config.add('test_color_config', ColorConfig('Test Color Config', gc9a01.BLACK))
        self.config.add('test_enum_config', EnumConfig('Test Enum Config', ['Option 1', 'Option 2', 'Option 3'], 'Option 1'))

        self.draw_status()

        try: # no os.path.exists function
            wifi_file = open('wifi.json')
        except OSError:
            ap = True
        else:
            ap = False

        if not ap:
            wifi_file = open('wifi.json')
            wifi_config = json.loads(wifi_file.read())
            wifi_file.close()
            self.ssid = wifi_config['essid']
            self.password = wifi_config['password']

        # TODO start random password generation and QRCode generation
        # on a thread and mark loading until complete
        if ap:
            self.password = generate_random_password()
            self.ssid = f'Badge {self.badge_id}'
        qr_data = QRData(f'WIFI:S:{self.ssid};T:WPA;P:{self.password};H:false;;'.encode(), mode=MODE_8BIT_BYTE)

        self.qr = QRCode()
        self.qr.add_data(qr_data) # WiFi QR code

        self.start_wifi(self.ssid, self.password, ap=ap)

        asyncio.create_task(self.start_website())

        print(f"Pre-fill, SSID is \"{self.ssid}\", password is {self.password}")

        while self.qr is None:
            sleep_ms(10)
        
        matrix = self.qr.get_matrix()
        if matrix is None or matrix[0] is None:
            self.draw_status("Error Generating")
            return
        
        self.display1.fill(gc9a01.WHITE)

        for y, row in enumerate(matrix):
            for x, value in enumerate(row): # type: ignore
                if value:
                    # TODO calculate width and height and scale?
                    self.display1.fill_rect(15+x*5, 15+y*5, 5, 5, gc9a01.BLACK)

    def start_wifi(self, essid, password, ap=True):
        import network

        if ap:
            ap = network.WLAN(network.AP_IF)
            ap.active(True)
            ap.config(essid=essid, authmode=network.AUTH_WPA_WPA2_PSK, password=password)

            while not ap.active():
                sleep_ms(10)

            MicroDNSSrv.Create({ '*' : ap.ifconfig()[0] })

            if_config = ap.ifconfig()
        
        else:
            sta_if = network.WLAN(network.STA_IF)
            sta_if.active(True)
            sta_if.connect(essid, password)

            while not sta_if.isconnected():
                sleep_ms(10)
        
            MicroDNSSrv.Create({ '*' : sta_if.ifconfig()[0] })

            if_config = sta_if.ifconfig()
        
        ip = if_config[0] if if_config and len(if_config) > 0 else 'Not Connected'

        self.controller.bsp.displays.display_center_text(
            ip,
            fg=gc9a01.BLACK,
            bg=gc9a01.WHITE,
            display_index=2
        )
    
    async def start_website(self):
        app = Microdot()

        Template.initialize('website/templates')

        Response.default_content_type = 'text/html'

        @app.route('/static/<path:path>')
        async def static(request, path):
            if '..' in path:
                # directory traversal
                return 'Not found', 404
            return send_file('/website/static/' + path, max_age=86400)

        @app.route('/')
        async def home(request):
            return Template('home.html').render(
                path='/',
                badge_id=self.badge_id,
                battery_voltage=str(self.controller.battery.mv_average.average()/100) + 'v',
                battery_percentage='{}%'.format(self.controller.battery.get_battery_percentage()),
                current_app=self.controller.current_view.name if self.controller.current_view else 'None',
            )



        @app.get('/add_app')
        async def add_app(request):
            # Get list of existing app files
            apps = [f[:-3] for f in os.listdir('apps') if f.endswith('.py') and f != '__init__.py']
            return Template('add_app.html').render(
                path='/add_app',
                apps=apps
            )

        @app.get('/get_app_code')
        async def get_app_code(request):
            app_name = request.args.get('app_name')
            if app_name:
                try:
                    with open(f'apps/{app_name}.py', 'r') as f:
                        return f.read()
                except:
                    return 'Error: App not found', 404
            return 'Error: No app specified', 400

        @app.post('/add_app/submit')
        @with_form_data
        async def handle_add_app(request):
            app_name = request.form['app_name']
            app_code = request.form['app_code']

            # Save the new app file
            with open(f'apps/{app_name}.py', 'w') as f:
                f.write(app_code)

        @app.get('/config')
        async def config(request):
            return Template('config.html').render(
                path='/config',
                rgb565_to_hex=rgb565_to_hex,
                app_configs=self.controller.app_configs.items()
            )
        
        
        @app.post('/config/update')
        @with_form_data
        async def update_config(request):
            print(request.form['appSelection'])
            app = request.form['appSelection']
            app_config = self.controller.app_configs[app]
            for config_name, value in request.form.items():
                if config_name not in app_config:
                    print(f"Skipping unknown config: {config_name} for app {app}")
                    continue
                existing_config = app_config[config_name]
                existing_type = type(existing_config)
                print(f"Updating {app} config: {config_name} = {value}")

                if existing_type is not str and existing_type is not int and 'type' in existing_config:
                    existing_config_type = existing_config['type']

                    # Convert value
                    if existing_config_type == 'BoolDropdownConfig':
                        # TODO weird hack for bools... fine for now, need to work it out better
                        # Don't ask :-) 
                        value = True if len(value) == 2 else False
                    else:
                        value = value[0]

                    
                    if existing_config_type == 'BoolDropdownConfig':
                        existing_config['current'] = value
                    if existing_config_type == 'EnumConfig':
                        existing_config['current'] = value
                    elif existing_config_type == 'ColorConfig':
                        existing_config['current'] = hex_to_rgb565(value)
                    elif existing_config_type == 'RangeConfig':
                        existing_config['current'] = int(value)
                elif existing_type is str:
                    self.controller.app_configs[app][config_name] = str(value[0])
                elif existing_type is int:
                    try:
                        self.controller.app_configs[app][config_name] = int(value[0])
                    except ValueError:
                        pass
                else:
                    print(f"Unknown config type for {app} {config_name}: {existing_type}")
                    

            # return Response.redirect('/config')
        app.run(port=80)

    def draw_status(self, status: str = 'Loading...'):
        self.display1.write(
            self.font,
            'Loading...',
            10,
            100,
            gc9a01.BLACK,
            gc9a01.WHITE
        )


if __name__ == "__main__":
    from single_app_runner import run_app
    run_app(App, perf=True)

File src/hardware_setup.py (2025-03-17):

# color_setup.py Customise for your hardware config

# Released under the MIT License (MIT). See LICENSE.
# Copyright (c) 2024 Peter Hinch

# As written, supports:
# gc9a01 240x240 circular display on Pi Pico
# Pin mapping is for Waveshare RP2040-Touch-LCD-1.28
# Edit the driver import for other displays.

# Demo of initialisation procedure designed to minimise risk of memory fail
# when instantiating the frame buffer. The aim is to do this as early as
# possible before importing other modules.

# WIRING
# Pico      Display
# GPIO Pin
# 3v3  36   Vin
# IO6   9   CLK  Hardware SPI0
# IO7  10   DATA (AKA SI MOSI)
# IO8  11   DC
# IO9  12   Rst
# Gnd  13   Gnd
# IO10 14   CS

from machine import Pin, SPI
import gc
from drivers.gc9a01.gc9a01 import GC9A01 as SSD

# from drivers.gc9a01.gc9a01_8_bit import GC9A01 as SSD

DC1 = 19
RST1 = 14
CS1 = 33

DC2 = 25
RST2 = 27
CS2 = 13

prst1 = Pin(RST1, Pin.OUT)
pcs1  = Pin(CS1, Pin.OUT)
pdc1  = Pin(DC1, Pin.OUT)

prst2 = Pin(RST2, Pin.OUT)
pcs2  = Pin(CS2, Pin.OUT)
pdc2  = Pin(DC2, Pin.OUT)

gc.collect()  # Precaution before instantiating framebuf
# See DRIVERS.md
spi = SPI(1, sck=Pin(10), mosi=Pin(11), miso=Pin(12), baudrate=60_000_000)
ssd1 = SSD(spi, dc=pdc1, cs=pcs1, rst=prst1, lscape=False, usd=False, mirror=False)
ssd2 = SSD(spi, dc=pdc2, cs=pcs2, rst=prst2, lscape=False, usd=False, mirror=False)

from gui.core.ugui import Display, quiet


nxt = Pin(0, Pin.IN, Pin.PULL_UP)  # Move to next control
# sel = Pin(16, Pin.IN, Pin.PULL_UP)  # Operate current control
# prev = Pin(18, Pin.IN, Pin.PULL_UP)  # Move to previous control
# increase = Pin(20, Pin.IN, Pin.PULL_UP)  # Increase control's value
# decrease = Pin(17, Pin.IN, Pin.PULL_UP)  # Decrease control's value


display1 = Display(ssd1, nxt, nxt)

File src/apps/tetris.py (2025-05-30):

import asyncio

import time
from apps.app import BaseApp
import random
import vga2_bold_16x32 as font 
import vga2_8x16 as font_small 
import framebuf

from single_app_runner import run_app
from drivers.displays import rgb
import gc9a01


class View(BaseApp):
    """
    Tetris
    """

    name = "Tetris"
    def __init__(self, controller):
        super().__init__(controller)
        self.controller.neopixel.fill((0, 0, 0))
        self.controller.neopixel.write()
        displays = self.controller.displays
        black = displays.COLOR_LOOKUP['fbuf']['black']
        displays.display1.fill(black)
        displays.display2.fill(black)
        self.rows = 20
        self.columns = 10
        self.block_size = 10
        self.next_block_size = 20
        self.score = 0
        self.lines = 0
        controller.bsp.speaker.start_song('tetris', repeat=True)
        self.grid = [[0 for column in range(self.columns)] for row in range(self.rows)]
        self.blocks = [
            [
                [1, 1, 1],
                [0, 1, 0]
            ],
            [
                [1, 1, 1, 1]
            ],
            [
                [0, 1, 1],
                [1, 1, 0]
            ],
            [
                [1, 1, 0],
                [0, 1, 1]
            ],
            [
                [1, 1, 1],
                [0, 0, 1]
            ],
            [
                [1, 1, 1],
                [1, 0, 0]
            ],
            [
                [1, 1],
                [1, 1]
            ]
        ]

        self.current_block = None
        self.is_game_over = False

        self.display1_mem_buf = bytearray(240*240*2)
        self.display1_fbuf_mv = memoryview(self.display1_mem_buf)
        self.display1_fbuf = framebuf.FrameBuffer(
            self.display1_mem_buf, 
            240, 
            240, 
            framebuf.RGB565
        )

        x_offset = round((self.controller.displays.display1.width() - (self.columns * self.block_size)) / 2)
        y_offset = round((self.controller.displays.display1.height() - (self.rows * self.block_size)) / 2)

        self.display1_fbuf.fill_rect(
            x_offset-5, 
            y_offset-5, 
            (self.columns * self.block_size)+10, 
            (self.rows * self.block_size)+10, 
            rgb((20, 20, 20))
        )
        self.next_block = random.choice(self.blocks)

        self.add_block()

    def button_press(self, button):
        if self.is_game_over:
            if button == 6:
                self.__init__(self.controller)
            return
        if button == 5:
            # Move left
            self.move_block_horizontal(-1)
            self.draw_scene()
        elif button == 4:
            # Move right
            self.move_block_horizontal(1)
            self.draw_scene()
        elif button == 0:
            # Mute Toggle
            if self.controller.bsp.speaker.state == 2: # AUDIO_PAUSED
                self.controller.bsp.speaker.resume_song()
            elif self.controller.bsp.speaker.state == 1: # AUDIO_PLAYING
                self.controller.bsp.speaker.pause_song()
    
    def button_click(self, button):
        if button == 6:
            # Rotate block and immediately redraw
            self.rotate_current_block()
            self.draw_scene()

    def button_long_press(self, button):
        if button == 6:
            # Drop the current block all the way down
            self.drop_current_block()
            self.draw_scene()

    def update_stats(self):
        displays = self.controller.displays
        black = displays.COLOR_LOOKUP['gc9a01']['black']
        white = displays.COLOR_LOOKUP['gc9a01']['white']
        red = displays.COLOR_LOOKUP['gc9a01']['red']
        self.controller.displays.display2.fill(black)
        if not self.is_game_over:
            x = round(self.controller.displays.display2.width()/4)
            y = 60
            self.controller.displays.display2.fill_rect(
                x-5, 
                y-5, 
                (len(self.next_block[0]) * self.next_block_size)+10, 
                (len(self.next_block) * self.next_block_size)+10, 
                gc9a01.color565(20, 20, 20)
            )
            for row_number, row in enumerate(self.next_block):
                for column_number, cell in enumerate(row):
                    if cell:
                        self.controller.displays.display2.fill_rect(x, y, self.next_block_size, self.next_block_size, red)
                    else:
                        self.controller.displays.display2.fill_rect(x, y, self.next_block_size, self.next_block_size, black)
                    x += self.next_block_size
                x = round(self.controller.displays.display2.width()/4)
                y += self.next_block_size
            self.controller.displays.display2.text(
                font_small,
                "Next",
                round(self.controller.displays.display2.width()/4),
                60 - font_small.HEIGHT,
                white,
                black
            )
        self.controller.displays.display2.text(
            font_small,
            f"Score: {self.score}",
            round(self.controller.displays.display2.width()/4),
            120,
            white,
            black
        )
        self.controller.displays.display2.text(
            font_small,
            f"Lines: {self.lines}",
            round(self.controller.displays.display2.width()/4),
            120 + font_small.HEIGHT,
            white,
            black
        )

    def add_block(self):
        block_width = len(self.next_block[0])
        x = round(self.columns/2 - block_width/2)
        y = 0

        self.current_block = {
            'x': x,
            'y': y,
            'block': self.next_block
        }

        if self.collision(x, y, self.next_block):
            asyncio.run(self.game_over())
            self.is_game_over = True
            return

        self.place_block_in_grid(self.current_block, 1)
        self.next_block = random.choice(self.blocks)
        self.update_stats()

    def place_block_in_grid(self, block_info, value):
        bx = block_info['x']
        by = block_info['y']
        shape = block_info['block']
        for row in shape:
            tx = bx
            for cell in row:
                if cell:
                    self.grid[by][tx] = value
                tx += 1
            by += 1
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

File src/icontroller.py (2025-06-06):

from bsp import BSP

from lib.smart_config import Config

# This is just a placeholder definition... should integrate with main app
class IApp:
    def __init__(self, controller):
        self.controller = controller
        self.config: Config = Config("")
        self.bsp = controller.bsp

    async def update(self):
        """
        Update the app. This method should be implemented in the derived class.
        """
        raise NotImplementedError("update method not implemented in the derived class.")

class IController:
    def __init__(self, hardware_version: str, displays):
        self._bsp = BSP(hardware_version, displays)
        self.current_view: IApp | None = None
        self.app_configs: dict[str, Config] = {}

    # TODO still have a circular import issue when we import AppDirectory....
    # @property
    # def app_directory(self) -> AppDirectory:
    #     """
    #     Returns the app directory instance.
    #     """
    #     return self._app_directory
    
    # @app_directory.setter
    # def app_directory(self, value: AppDirectory):
    #     """
    #     Sets the app directory instance.
    #     """
    #     self._app_directory = value
    

    @property
    def bsp(self):
        return self._bsp

    # TODO still here for backwards compatbility...
    @property
    def neopixel(self):
        return self._bsp.leds.leds

    # TODO still here for backwards compatbility...
    @property
    def displays(self):
        return self._bsp.displays

    def is_current_app(self, app_instance):
        """
        Check if the given app instance is the current app.
        """
        raise NotImplementedError("is_current_app method not implemented in the derived class.")
    
    async def switch_app(self, app_name: str):
        """
        Switch to the specified app. This method should be implemented in the derived class.
        """
        raise NotImplementedError("switch_app method not implemented in the derived class.")
    

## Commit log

2025-02-06 Add board schematic
2025-02-15 Add views/add library for accelerometer
2025-02-15 Debounce buttons
2025-02-16 Change button order for tetris, show score/lines on game over screen
2025-03-04 Add files via upload
    Screen protection stl files
    [BSides2025-ScreenBezel.stl, BSides2025-ScreenSupport.stl]
2025-03-04 All Revisions of Screen Protection
    [BSides2025-ScreenBezel.stl, BSides2025-ScreenBezelV3.stl, BSides2025-ScreenSupport.stl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]
2025-03-05 New Version of Bezel and Support with Clips
    [BSides2025-ScreenBezelV4.stl, BSides2025-ScreenSupportV5.stl]
2025-03-05 Get V2 board working, improve main view
2025-03-05 fix retry button in tetris
    [view1.py]
2025-03-07 Restore main button switching functionality
2025-03-07 Revert to normal mapping
    [view0.py]
2025-03-07 Fix 2x speed playback
    [audio.py]
2025-03-07 Make button passthrough use class argument
2025-03-09 Modified Screen Support STL (v6)
    [BSides2025-ScreenSupportV6.stl]
2025-03-13 update led test and led class
2025-03-17 Modified screen protector
    [BSides2025-ScreenBezelV5.stl, BSides2025-ScreenBezelV6.stl, BSides2025-ScreenBezelV7.stl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]
2025-03-18 fix a couple additional md formatting
2025-03-19 Update neopixel typing, fix LED timings, increase display SPI speed
    [displays.py, leds.py, test_spinner.py]
2025-03-19 Update LED timings and tests
2025-03-19 More LED driver updates
2025-03-20 Add ScreenCover STLs
    [BSides2025-ScreenCover.stl, BSides2025-ScreenCoverV2.stl, BSides2025-ScreenCoverV3.stl]
2025-03-26 Fix time typings, update views to be async, fix hello world view
    [analog_clock.py, buttons.py, hello_world_app.py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]
2025-03-30 Made release and long press work for button 1, added button test function, more config updates, longer LED timings
2025-03-30 Improve button tester, add V3 buttons
2025-03-31 Make base BSP holder class to avoid the inheritance dependency issue and allow for better typing in apps
    [app.py, bsp.py, displays.py]
2025-03-31 Remove erronous gitignore, add unit test frameworks, move http_server
2025-04-02 Typing updates, app fixes, etc
    [app.py, app_directory.py, bsp.py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]
2025-04-02 Clean up some print statements
2025-04-02 Add files via upload
    This file is the final battery cover that is customized to the bulk batteries that have been purchased.
    [Badge Battery Cover 4.stl]
2025-04-08 New version of the battery cover and 3mf file with both screen and battery covers
    [BSides2025-Badge_Covers.3mf, BSides2025_Battery_Cover_V4.stl]
2025-04-18 Makes tetris work for V4, uses framebuffer, and also adjust how buttons work
2025-04-18 IMU updates, apps, etc
2025-04-19 Fix tetris colors, remove color swap
    [displays.py, menu.py, single_app_runner.py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]
2025-04-23 modified imperial_march.py, added animation and LEDs
2025-04-23 Add Python gc9a01 driver for testing
2025-05-01 Updated screen Cover
    [1.28_TFT_screen_cover_V4.stl]
2025-05-01 Updated bezel 3mf
    [BSides2025-ScreenBezelV4.3mf]
2025-05-09 Remove tester that is replaced by apps
    [menu.py]
2025-05-09 Update_Cleanup STLs
    [BSides2025-ScreenBezel.stl, BSides2025-ScreenBezelV2.stl, BSides2025-ScreenBezelV3.stl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]
2025-05-09 Add menu teardown, lucky number fix
    [menu.py]
2025-05-10 Add mute button to tetris
2025-05-16 Add battery monitor
2025-05-28 Fixing file path and form reset for compatibility with Badger2040
    [badger_gui.py]
2025-05-28 Fixing file path for name.json on Gigtel badges
    [badger_gui.py]
2025-05-30 Update tools.py with correct badge renamer
    [tools.py]
2025-06-02 Make pressing buttons prevent the board from sleeping
2025-06-03 Working startup on new firmware without speaker issues
    [audio.py]
2025-06-04 Update battery scale
2025-06-06 Add time to badge app, fix sleep
    [view0.py]
2025-06-06 Config updates, driver base class, split up README
2025-06-06 Remove print statement
2025-06-08 Adjust battery voltage based on resistor divider on the schematic. Scaled voltages used for battery percentage by same resistor divider scaler.
